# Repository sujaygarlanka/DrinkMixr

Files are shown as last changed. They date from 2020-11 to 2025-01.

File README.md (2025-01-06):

# DrinkMixr



A friend and I built a drink mixing machine that can dispense up to 4 liquids with half an ounce accuracy in any combination. There are three parts to this project.
- [Drink Machine](#drink-machine)
- [Mobile App](#mobile-app)
- [API](#api)

## Drink Machine
A physical machine that is 3D printed and MDF cut and contains tubing and motors controlled by a Raspberry Pi. It runs embedded python code that can be found [here](https://github.com/sujaygarlanka/DrinkMixr-Raspberry-Pi).

Final Machine              |  3D Model
:-------------------------:|:-------------------------:
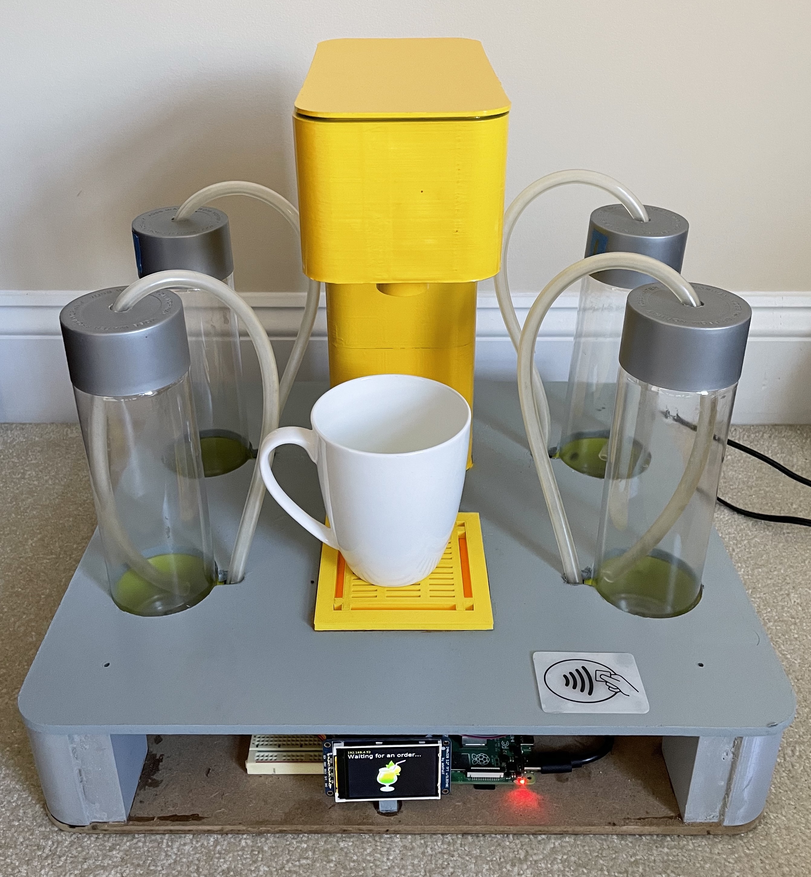
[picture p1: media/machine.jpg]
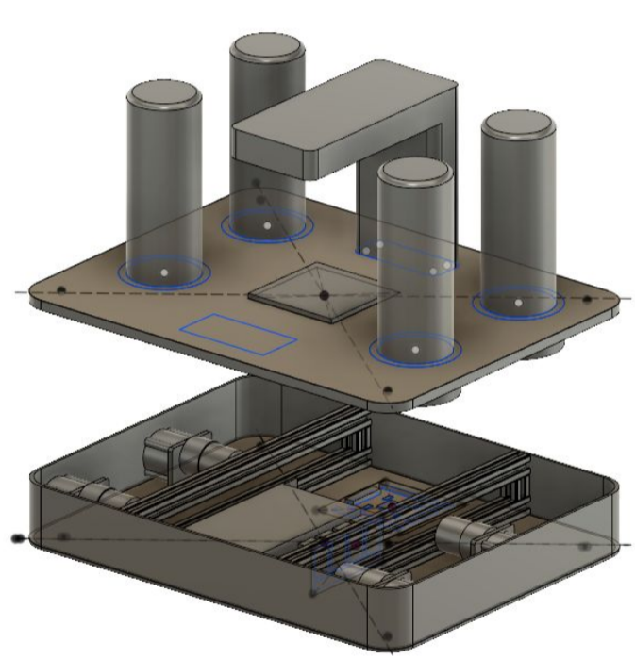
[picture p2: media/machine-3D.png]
 |  

## Mobile App


A mobile built in React Native that allows you to customize, save and send recipes to the drink machine when you tap your phone to the machine. Code for the 
app can be found [here](https://github.com/sujaygarlanka/DrinkMixr/tree/master/mobile_app).

## API
An API written in Python Flask running on a heroku server that accepts orders sent from the mobile app, queues them and sends them to the machine when it is ready to dispense. This API also handles the creation of users, tracking how much a user drinks, storing machine settings, etc. The API uses a MongoDB database to store all information.

### API Doc:
```python
@app.route('/order', methods=['GET'])
def getOrder():
    """
    GET /order
    Get the first order in the queue.

    Returns:
        JSON: The first order in the queue.
    """
    pass

@app.route('/order', methods=['POST'])
def addOrder():
    """
    POST /order
    Add an order to the end of the queue.

    Request Body:
        JSON: The order details.

    Returns:
        200 OK: If the order was successfully added.
        400 Bad Request: If the order data is missing or invalid.
    """
    pass

@app.route('/user', methods=['POST'])
def createUser():
    """
    POST /user
    Create a new user.

    Request Body:
        JSON: Contains the user's name.

    Returns:
        200 OK: If the user was successfully created.
        400 Bad Request: If the name is missing in the request body.
    """
    pass

@app.route('/configuration', methods=['GET'])
def getConfiguration():
    """
    GET /configuration
    Get the current Drink Mixr ingredients and motor configurations.

    Returns:
        JSON: The current configuration.
        200 OK: If the configuration is successfully retrieved.
    """
    pass

@app.route('/ingredients', methods=['PUT'])
def updateIngredients():
    """
    PUT /ingredients
    Update the ingredients in the Drink Mixr.

    Request Body:
        JSON: The updated ingredient list.

    Returns:
        204 No Content: If the update was successful.
    """
    pass

@app.route('/motors', methods=['PUT'])
def updateMotors():
    """
    PUT /motors
    Update the motor configurations in the Drink Mixr.

    Request Body:
        JSON: The updated motor configurations.

    Returns:
        204 No Content: If the update was successful.
    """
    pass

@app.route('/tubes', methods=['PUT'])
def updateTubes():
    """
    PUT /tubes
    Update the volume in the Drink Mixr's tubes.

    Request Body:
        JSON: The updated tube volume information.

    Returns:
        204 No Content: If the update was successful.
    """
    pass

@app.route('/recipes', methods=['GET'])
def getRecipes():
    """
    GET /recipes
    Retrieve all recipes for a specific user.

    Query Parameters:
        user_name (str): The name of the user.

    Returns:
        JSON: A list of recipes for the specified user.
        200 OK: If the recipes are successfully retrieved.
        400 Bad Request: If the user name is missing.
    """
    pass

@app.route('/recipes', methods=['POST'])
def addRecipe():
    """
    POST /recipes
    Add or update a recipe for a user.

    Query Parameters:
        user_name (str): The name of the user.

    Request Body:
        JSON: The recipe details.

    Returns:
        JSON: Confirmation of the added or updated recipe.
        200 OK: If the operation was successful.
        400 Bad Request: If the user name is missing.
    """
    pass

@app.route('/recipes', methods=['DELETE'])
def deleteRecipe():
    """
    DELETE /recipes
    Delete a specific recipe for a user.

    Query Parameters:
        user_name (str): The name of the user.
        recipe_name (str): The name of the recipe to delete.

    Returns:
        JSON: Confirmation of the deleted recipe.
        200 OK: If the recipe is successfully deleted.
        400 Bad Request: If the user name or recipe name is missing.
    """
    pass
```

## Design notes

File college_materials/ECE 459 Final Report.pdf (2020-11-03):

## Final Report

Final system specifications

The idea of the project is to build a drinker mixer machine that allows users to create and order drink recipes using an iOS app that communicates with a server that sends the order to an Arduino which then controls four pumps to dispense liquid into a cup.

The user can use the phone app save, edit, and delete custom recipes and order drinks based off these recipes. When a user wants to make an order, he/she taps their phone to an NFC tag that allows the app to send an order to a server. The Arduino Uno R3 uses a WiFi module that reads orders from the server and the Arduino parses the data to control the appropriate peristaltic pumps based on the ingredients in the order. During drink order processing, the order details are shown through a TFT display and prompts the user to place a cup under the nozzle. The cup is detected using a ultrasonic sensor. The volume of liquid dispensed will be controlled by the microcontroller via timers. Additionally, the TFT display shows user data such as total amount consumed.

Key progress from previous week

Over the previous week, we soldered all of our components onto our PCB and built the final chassis. Building the final chassis included laser cutting out top, bottom, and sides of our base. In addition, we 3D printed the neck and head. We also updated the phone app to support adding, saving, editing, and deleting recipes. Finally, we integrated all of the components with the chassis.

Open problems

The biggest open problem we have is not being able to accurately dispense when the motors are on. We suspect that this is due to interference with the Arduino through a common ground between the motors, power supply, and Arduino. When the relays are not connected to the common ground, the timing of the motors are accurate. Our efforts to resolve this would be to separate the grounds of the 15V power supply, buck converter and Arduino.

Currently, the output of the flow sensors are not accurate when the motors are running, we the motors are disconnected, the flow sensors perform as expected. We found there was interference from the common ground between the motors and the Arduino. We tried using tinfoil to act as a radiant shield for the signal wire but that did not work well.

We are limited to sending a payload of 64 bytes from the WiFi module to the serial buffer of the Arduino. We tried to read the payload as the WiFi module was sending it but were unable to find a consistent, working solution.

Testing & Results
- Accuracy tests were conducted for several volume amounts for water and juice.
- Timing and flow sensor methods were tested (timing was more accurate)
- Surface tension was achieved for 1 oz to 1 cup for various combinations of water volumes
- We confirmed pumping accuracy within 0.1 oz for water
- We used Postman to send HTTP requests to test the server side processing.

Robustness

The phone app checks for invalid data in volume field for recipes and any recipe name with ASCII characters is supported. The app converts spaces to underscores in order to send valid HTTP requests. Currently, the machine does not keep track of source volume so it does not detect when the source is empty or when the user orders a drink that has more volume than the source. Also, if a recipe has an ingredient an ingredient not in stock, the app currently does not check for that. This can be easily implemented by fetching from the database which items are in stock and check with the order when the user hits send.

Final vs. Initial Specifications:
- Server: The server used to process HTTP requests is a Python Flask server (https://stark-beach-45459.herokuapp.com/). A MongoDB database stores user recipes, amount consumed, ingredients, and orders. Our goal was to make are endpoints work correctly, and there are currently no bugs we have found. The following endpoints were created:
- GET /order
- POST /order
- POST /user
- GET /ingredients
- GET /recipes
- POST /recipes
- DELETE /recipes
- Mobile App: we created an iOS app that the user interfaces with to create, edit, delete and send custom recipes as drink orders. If the user wants to add a new recipe, they start from a template recipe that contains all of the ingredients in stock and they can change the volumes. This was our goal initially and were able to achieve it. One significant change we made involved using the phone as a reader vs. as a tag. Initially, the idea was to use an NFC reader to read the phone’s RFID tag and send data through NFC. We found it was not possible to do this with our phones (it could be done with a Nexus 5). We switched to using the phone as a reader and send data through WiFi. This turned out to be easier to facilitate communication between the phone, server, and Arduino.

- PCB: our PCB is used to integrate our Arduino with its peripherals in a compact, robust fashion. We used header pins to mount the Arduino, WiFi module, and buck converter. We soldered the rest of the components via wires. Ideally, we would want to recreate our own Arduino but our general goal was to integrate without a breadboard and this goal was met.
- Chassis: the chassis was designed to house all electrical components in an enclosed basement chamber that doubles as the main frame of the device. The peristaltic pumps reside in this basement as well, with their tubing routed through the hollow neck of the device. To house liquid ingredients, there are four plastic cylindrical reservoirs that flank the center dispenser console. These containers are supported by 3D-printed support frames that are integrated into the basement chamber. A beverage plate resides at the center of the device that serves as an outlet for any leaks and drippage that occurs after dispensing.

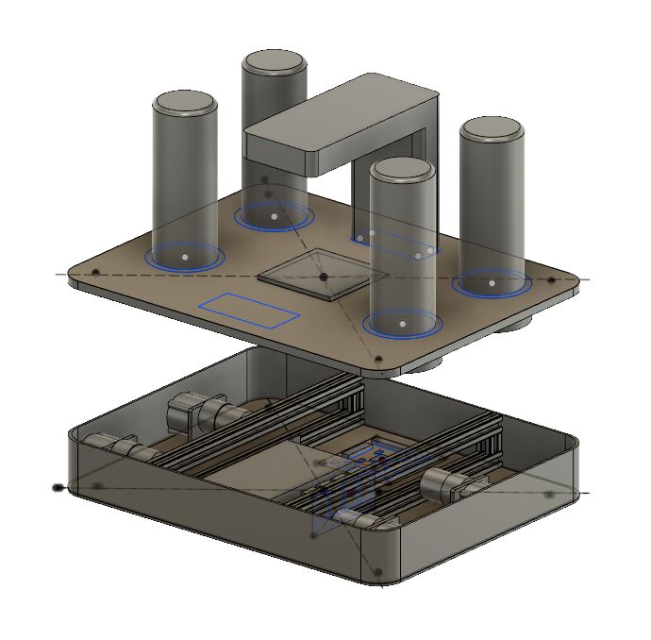
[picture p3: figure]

Safety considerations

The tubing is food safe and the sealant used at the bottom of the sources is also food safe. Given more time, we would fully isolate the electrical components from the food components like the tubing.

Final Gantt Chart

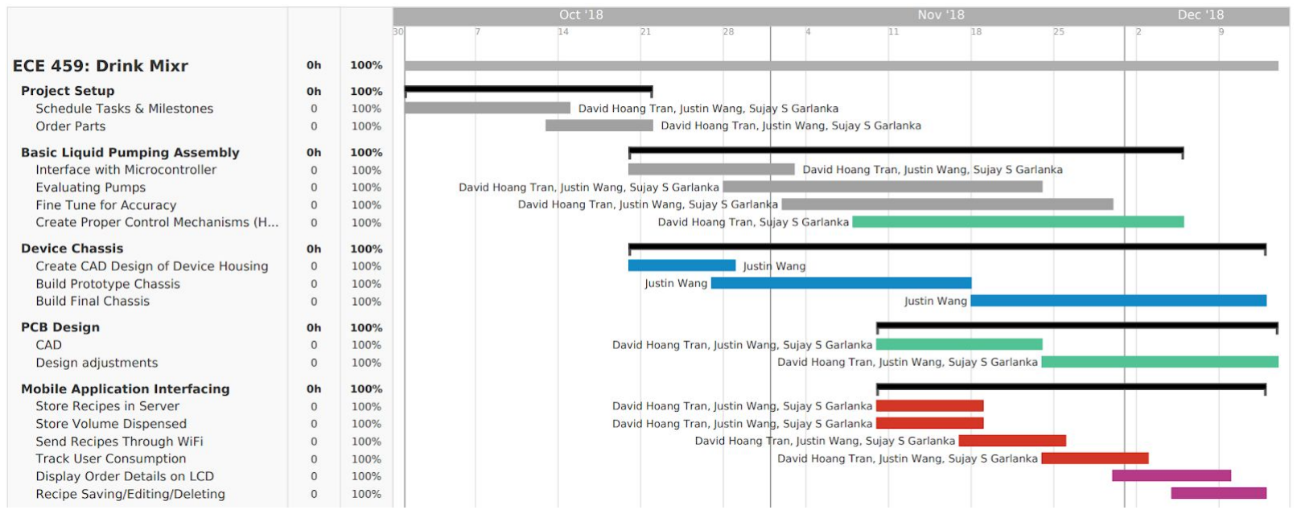
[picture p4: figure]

Final vs Initial Gantt chart
- Deviations: We added more subtasks for the phone app in order to organize developing the recipe customization. We needed to extend the deadline for testing & fine tuning flow meters since we wanted to use the temperature flow meters for liquids of different viscosity. We also extended the deadline for final chassis because it took longer than expected due to 3D print times and laser cutting issues.

Final budget
- Total spent: $520
- Cost to reproduce: $421

Technical problems encountered (and how were they overcome)

- Payload parsing: The server sends an order to the Arduino as a string of 64 bytes. An example payload would be
$O:robot-456.3:water_0-0-14.575:water_1-1-5.0:water_2-2-2.7:$. The format of the payload is “O:user_name-amount drank-ingredient-motor number-dispense time (sec):[additional ingredient entries]”. Here, robot is the name of the user and 456.3 is the total about consumed by the user. water_0 is the name of the ingredient, 0 is the motor number, and 14.575 is the dispense time of this ingredient in seconds. We parse the input by splitting by colons and dashes.
- Pumping accuracy with motors powered on: we ran into an issue with motor accuracy whenever we connected the motors to the 15V power supply. We believed the issue was caused by interference with the Arduino through a common ground between the motor and Arduino grounds.
- Parallel motor controls: we solved the problem of running motors simultaneously by keeping track of when a motor has been turned on. This was done in the Arduino code by storing the timestamp at which a motor turned on and iteratively checking each motor’s start time with the current timestamp.
- App functionality: a technical problem we resolve involved keeping the app up to date whenever the user creates/edits/deletes a recipe. We added a save button so that the user can either discard unsaved changes or save them. Whenever a user deletes a recipe, the page automatically returns to the home screen with the recipe deleted. Making sure the home screen has a correct list always was a challenge due to HTTP requests taking longer than page switching. We need to make sure the app waits for the request to complete or refresh the page automatically once it completes.

Rev 2.0
- Use H-bridges for reverse flow in order to save liquid in the tube and prevent contamination.
- Transfer bigger recipes by partitioning payload or be able to read payload as it’s being sent from WiFi module to the serial buffer.
- Not use a T-junction and use four flow sensors, which enables four motors to be run in parallel.

Member contributions
- Sujay
- Integrated Wifi module, TFT display and relays with the Arduino
- Helped design PCB
- Set up Python Flask server for the API
- Developed NFC functionality of the mobile app
- Justin
- Developed a prototype and final chassis
- Design of the liquid reservoir pipeline
- Component design and selection
- Tested thermal mass flow rate sensors
- David
- Developed the PCB schematic and layout using Eagle.
- Developed interface and functionality of the mobile app allowing users to create, edit, delete, and send orders.
- Helped test NFC for the original plan of reading RFID tags in phones
- Helped test accuracy of pumps and flow sensor signalling

Components:

power supply | 14.99
4 channel relay | 7.86
4 pumps | 123.58
1 tube | 9.99
2 flow meters | 45.48
arduino uno | 10
5V regulator | 9.99
variable buck converter | 7.99
TFT LCD | 31.28
wifi module (huzzah) | 16.95
4 VOSS bottles | 5
PING | 10
PCB | 27.88
Chassis parts | 100
h-bridges | 30
RC522 | 5.49
large flow meter | 19.64
expensive flow meters (2) | 74
DIYall ESP8266 | 6.99
Additional tubing | 20
4 wifi modules (Maker focus) | 13.99

ESP8266 802.11 (Adafruit) 14.93

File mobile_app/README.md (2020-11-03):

# Drink Mixr App

Special Steps Taken
------
- Add to react native vector icons to project
    - https://github.com/oblador/react-native-vector-icons#ios
- Google Sign In

UI
------
React Native Paper
- https://callstack.github.io/react-native-paper/getting-started.html

Galio
- https://github.com/galio-org/galio
- https://github.com/galio-org/galio-starter-kit

Authentication 
------
Google Sign In
- https://www.npmjs.com/package/react-native-google-signin
- https://aboutreact.com/example-of-google-sign-in-in-react-native/

React Native - Tutorials
------
App Organization
- https://medium.com/the-react-native-log/organizing-a-react-native-project-9514dfadaa0

Props and State in React.js
- https://www.youtube.com/watch?v=_D1JGNidMr4

React Navigation
- https://facebook.github.io/react-native/docs/navigation#react-navigation
https://alligator.io/react/react-native-navigation/

Authentication
- https://blog.usejournal.com/persisting-user-authentication-in-a-react-native-app-778e028ac816
- https://reactnavigation.org/docs/auth-flow/
- https://github.com/facebook/react-native-fbsdk

Redux
- https://www.youtube.com/watch?v=KTOoHu7kJTY

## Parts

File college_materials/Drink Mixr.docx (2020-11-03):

# Parts and Materials

Pumping System:

Part | Quantity | Cost ($) | Delivery Status
Power Supply (https://www.amazon.com/SMAKN-Adaptor-Transformers-adapters-chargers/dp/B0754X9P3N) | 1 | 14.99 | Delivered
Power Distribution (https://www.amazon.com/gp/product/B01CU66VM2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) | 1 | 16.50 | Delivered
H-Bridges (https://www.digikey.com/product-detail/en/adafruit-industries-llc/3190/1528-1719-ND/6138098?WT.srch=1) | 4 | 30 | Delivered
Persistaltic Pump (https://www.ebay.com/itm/12V-400ml-min-Peristaltic-Pump-Dosing-Pump-Vacuum-Aquarium-Lab-Analytical-Water/122421770219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) Other Motor (https://www.ebay.com/itm/DC-12V-400ml-min-Aquarium-Lab-AnalyticaDosing-Pump-Peristaltic-Pump-For-l-Water/263975802514) | 3 1 | 123.58 | Delivered

Electronics:

Part | Quantity | Cost ($) | Delivery Status
Arduino | 1 | 10 | Delivered
PN532 (https://www.amazon.com/gp/product/B00KKUECAO/ref=od_aui_detailpages00?ie=UTF8&psc=1) (NFC) | 1 | 37.97 | Delivered
RC522 (https://www.amazon.com/gp/product/B01CSTW0IA/ref=oh_aui_detailpage_o06_s00?ie=UTF8&psc=1) (NFC) | 1 | 5.49 | Delivered
TFT Display (https://www.adafruit.com/product/1480) | 1 | 31.28 | Expected Delivery Monday
5V Regulator (https://www.adafruit.com/product/1385) | 1 | 9.95 | Delivered
Flow Rate Meter (https://www.digikey.com/product-detail/en/314150001/1597-1615-ND/5488169?so=57078285) | 2 | 45.48 | Delivered
Flow Rate Sensor (Adafruit) (https://www.adafruit.com/product/828) | 1 | 19.64 | Delivered
Flow Rate Meters | 2 | 74 | Delivered
Relays (co-lab) | 2 | 4 | Delivered
4 Channel Relay (https://www.amazon.com/dp/B01HEQF5HU/ref=biss_dp_t_asn) | 1 | 7.86 | Expected Delivery Friday
WiFi Module (https://www.amazon.com/DIYmall-ESP8266-ESP-01S-Serial-Transceiver/dp/B00O34AGSU) (Feather Huzzah) | 1 | 16.95 (Ocean Engineering) | Delivered
PING Sensor | 1 | 10 (Bingham) | Delivered
DIYmall ESP8266 ESP-01S (https://www.amazon.com/gp/product/B00O34AGSU/ref=oh_aui_detailpage_o02_s00?ie=UTF8&psc=1) | 1 | 6.99 | Delivered
4 WIFI Modules (Makerfocus) (https://www.amazon.com/Makerfocus-ESP8266-ESP-01S-Transceiver-Arduino/dp/B01N98BTRH?s=electronics) | 1 | 13.99 | Expected Delivery Saturday
Adafruit ESP8266 802.11 (https://www.amazon.com/gp/product/B0131V0WYI/ref=oh_aui_detailpage_o01_s00?ie=UTF8&psc=1) | 1 | 14.93 | Delivered
Variable Buck Converter (https://www.amazon.com/gp/product/B00SY37S00/ref=oh_aui_detailpage_o00_s00?ie=UTF8&psc=1) | 1 | 7.99 | Expected Delivery Friday

Chassis:

Part | Quantity | Cost ($) | Delivery Status
Silicon Tubing (https://www.amazon.com/gp/product/B0754KH4KP/ref=oh_aui_detailpage_o05_s00?ie=UTF8&psc=1) (too large) | 1 | 12.99 | Delivered
Silicon Tubing (https://www.amazon.com/gp/product/B01N3QTNTM/ref=oh_aui_detailpage_o00_s00?ie=UTF8&psc=1) (right size, not food safe) | 1 | 7.29 | Delivered
Silicon Tubing (3/16”, 10 ft) (https://www.amazon.com/gp/product/B017EA5ST6/ref=oh_aui_detailpage_o00_s00?ie=UTF8&psc=1) - too thick | 1 | 8.69 | Delivered
Vinyl Tubing (1/4“) | 1 | 21.00 | Delivered
Silicon Tubing (4mm ID, food safe) (https://www.amazon.com/Silicone-Tubing-16-ID-Wall/dp/B079X1S5WP?s=industrial) | 1 | 9.99 | Expected Tuesday Dec. 2
Funnel (https://www.amazon.com/gp/product/B01NH53RBH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) | 1 | 8.98 | Need to order/make
Old Bottles | 6 | 18 | Delivered
New Bottles | 4 | 15 | Delivered

Total Spent: $696

Cost to rebuild: $420.99

# Reimbursement

David:

Part | Cost ($)
Peristaltic Pumps (3) | 92.64
Silicon Tubing (3/16”, 10 ft) (https://www.amazon.com/gp/product/B017EA5ST6/ref=oh_aui_detailpage_o00_s00?ie=UTF8&psc=1) | 8.69
Best Tubing (1/4“) | 21.00
DIYmall ESP8266 ESP-01S (https://www.amazon.com/gp/product/B00O34AGSU/ref=oh_aui_detailpage_o02_s00?ie=UTF8&psc=1) | 6.99
ESP8266 802.11 (https://www.amazon.com/gp/product/B0131V0WYI/ref=oh_aui_detailpage_o01_s00?ie=UTF8&psc=1) | 14.93

Sujay

Part | Cost ($)
Peristaltic Pump | 30.88
Silicon Tubing (large and plasticky) | 12.99
Silicon Tubing (rubbery and on Amazon) | 7.29
Flow Rate Sensor (Digikey) (Ebay) | 22.74
Flow Rate Sensor (Adafruit) | 19.64
PN532 | 37.97
Relay | 2
Variable Buck Converter | 7.99
4 Channel Relay | 7.86
TFT Display | 31.28

Justin:

Part | Cost
Bottles | ?

# Need to Return

Part | Cost
Flow Rate Sensor (Adafruit) | 19.64
NFC Reader (https://www.amazon.com/gp/product/B00KKUECAO/ref=od_aui_detailpages00?ie=UTF8&psc=1) | 39.97
DIYmall ESP8266 ESP-01S (https://www.amazon.com/gp/product/B00O34AGSU/ref=oh_aui_detailpage_o02_s00?ie=UTF8&psc=1) | 6.99
ESP8266 802.11 (https://www.amazon.com/gp/product/B0131V0WYI/ref=oh_aui_detailpage_o01_s00?ie=UTF8&psc=1) | 14.93
Silicon Tubing (3/16”, 10 ft) (https://www.amazon.com/gp/product/B017EA5ST6/ref=oh_aui_detailpage_o00_s00?ie=UTF8&psc=1) - too thick | 8.69

# Useful Links

Hacker Shack Drink Mixer (good parts reference): https://www.youtube.com/watch?v=2DopvpNF7J4&t=486s

GreatScott! Cocktail Machine (400ml/min motors): https://www.youtube.com/watch?v=Z7GkGeZrb2Y&t=417s

Wifi Module:

https://medium.com/@cgrant/using-the-esp8266-wifi-module-with-arduino-uno-publishing-to-thingspeak-99fc77122e82

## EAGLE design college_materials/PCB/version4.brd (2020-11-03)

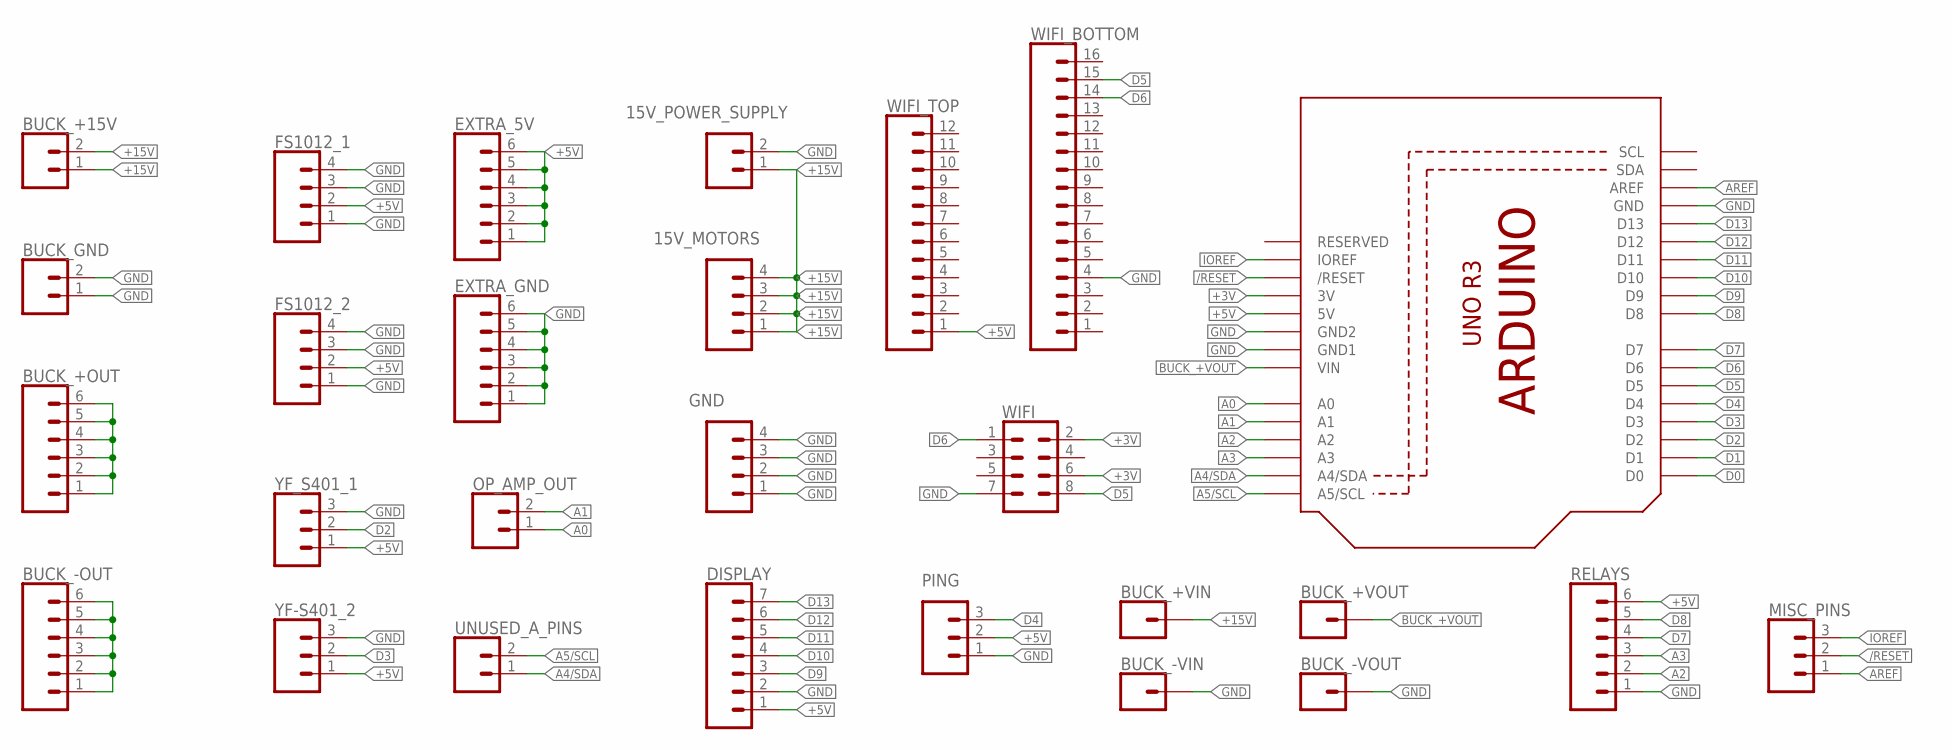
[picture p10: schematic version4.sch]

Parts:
15V_MOTORS: CONN_04; 1X04
15V_POWER_SUPPLY: CONN_02; 1X02
BUCK_+15V: CONN_02; 1X02
BUCK_+OUT: CONN_06SILK_FEMALE_PTH; 1X06
BUCK_+VIN: CONN_01; 1X01
BUCK_+VOUT: CONN_01; 1X01
BUCK_-OUT: CONN_06SILK_FEMALE_PTH; 1X06
BUCK_-VIN: CONN_01; 1X01
BUCK_-VOUT: CONN_01; 1X01
BUCK_GND: CONN_02; 1X02
DISPLAY: CONN_07; 1X07
EXTRA_5V: CONN_06SILK_FEMALE_PTH; 1X06
EXTRA_GND: CONN_06SILK_FEMALE_PTH; 1X06
FS1012_1, FS1012_2: CONN_04; 1X04
GND: CONN_04; 1X04
MISC_PINS: CONN_03; 1X03
OP_AMP_OUT: CONN_02; 1X02
PING: CONN_03; 1X03
RELAYS: CONN_06SILK_FEMALE_PTH; 1X06
U1: ARDUINOR3-BPLACE
UNUSED_A_PINS: CONN_02; 1X02
WIFI: CONN_04X2; 2X4
WIFI_BOTTOM: CONN_16; 1X16
WIFI_TOP: CONN_12; 1X12
YF-S401_2: CONN_03; 1X03
YF_S401_1: CONN_03; 1X03

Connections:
+3V: U1.3V, WIFI.2, WIFI.6
+5V: DISPLAY.1, EXTRA_5V.1, EXTRA_5V.2, EXTRA_5V.3, EXTRA_5V.4, EXTRA_5V.5, EXTRA_5V.6, FS1012_1.2, FS1012_2.2, PING.2, RELAYS.6, U1.5V, WIFI_TOP.1, YF-S401_2.1, YF_S401_1.1
+15V: 15V_MOTORS.1, 15V_MOTORS.2, 15V_MOTORS.3, 15V_MOTORS.4, 15V_POWER_SUPPLY.1, BUCK_+15V.1, BUCK_+15V.2, BUCK_+VIN.1
/RESET: MISC_PINS.2, U1.RESET (/RESET)
A0: OP_AMP_OUT.1, U1.A0
A1: OP_AMP_OUT.2, U1.A1
A2: RELAYS.2, U1.A2
A3: RELAYS.3, U1.A3
A4/SDA: U1.A4 (A4/SDA), UNUSED_A_PINS.1
A5/SCL: U1.A5 (A5/SCL), UNUSED_A_PINS.2
AREF: MISC_PINS.1, U1.AREF
BUCK_+VOUT: BUCK_+VOUT.1, U1.VIN
D0: U1.D0
D1: U1.D1
D2: U1.D2, YF_S401_1.2
D3: U1.D3, YF-S401_2.2
D4: PING.3, U1.D4
D5: U1.D5, WIFI.8, WIFI_BOTTOM.15
D6: U1.D6, WIFI.1, WIFI_BOTTOM.14
D7: RELAYS.4, U1.D7
D8: RELAYS.5, U1.D8
D9: DISPLAY.3, U1.D9
D10: DISPLAY.4, U1.D10
D11: DISPLAY.5, U1.D11
D12: DISPLAY.6, U1.D12
D13: DISPLAY.7, U1.D13
GND: 15V_POWER_SUPPLY.2, BUCK_-VIN.1, BUCK_-VOUT.1, BUCK_GND.1, BUCK_GND.2, DISPLAY.2, EXTRA_GND.1, EXTRA_GND.2, EXTRA_GND.3, EXTRA_GND.4, EXTRA_GND.5, EXTRA_GND.6, FS1012_1.1, FS1012_1.3, FS1012_1.4, FS1012_2.1, FS1012_2.3, FS1012_2.4, GND.1, GND.2, GND.3, GND.4, PING.1, RELAYS.1, U1.GND, U1.GND1, U1.GND2, WIFI.7, WIFI_BOTTOM.4, YF-S401_2.3, YF_S401_1.3
IOREF: MISC_PINS.3, U1.IOREF
unnamed: BUCK_+OUT.1, BUCK_+OUT.2, BUCK_+OUT.3, BUCK_+OUT.4, BUCK_+OUT.5, BUCK_+OUT.6
unnamed: BUCK_-OUT.1, BUCK_-OUT.2, BUCK_-OUT.3, BUCK_-OUT.4, BUCK_-OUT.5, BUCK_-OUT.6

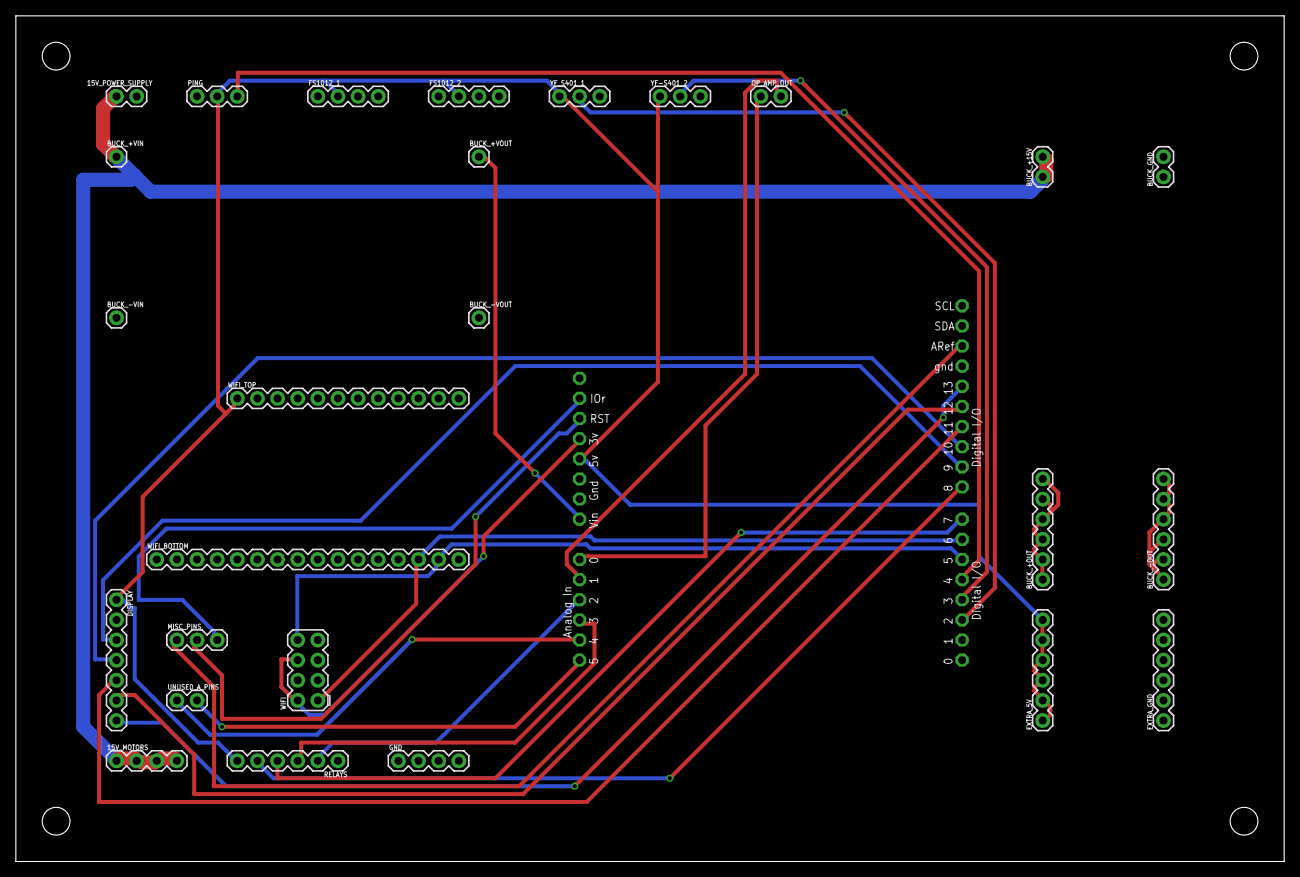
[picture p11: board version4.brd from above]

Board: 2 copper layers, 160.0 x 106.7 mm, 27 parts (0 on the bottom side), 28 nets.

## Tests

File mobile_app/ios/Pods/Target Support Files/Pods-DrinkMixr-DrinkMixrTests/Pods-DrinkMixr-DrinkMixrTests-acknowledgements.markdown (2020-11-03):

# Acknowledgements
This application makes use of the following third party libraries:

## AppAuth

                                 Apache License
                           Version 2.0, January 2004
                        http://www.apache.org/licenses/

   TERMS AND CONDITIONS FOR USE, REPRODUCTION, AND DISTRIBUTION

   1. Definitions.

      "License" shall mean the terms and conditions for use, reproduction,
      and distribution as defined by Sections 1 through 9 of this document.

      "Licensor" shall mean the copyright owner or entity authorized by
      the copyright owner that is granting the License.

      "Legal Entity" shall mean the union of the acting entity and all
      other entities that control, are controlled by, or are under common
      control with that entity. For the purposes of this definition,
      "control" means (i) the power, direct or indirect, to cause the
      direction or management of such entity, whether by contract or
      otherwise, or (ii) ownership of fifty percent (50%) or more of the
      outstanding shares, or (iii) beneficial ownership of such entity.

      "You" (or "Your") shall mean an individual or Legal Entity
      exercising permissions granted by this License.

      "Source" form shall mean the preferred form for making modifications,
      including but not limited to software source code, documentation
      source, and configuration files.

      "Object" form shall mean any form resulting from mechanical
      transformation or translation of a Source form, including but
      not limited to compiled object code, generated documentation,
      and conversions to other media types.

      "Work" shall mean the work of authorship, whether in Source or
      Object form, made available under the License, as indicated by a
      copyright notice that is included in or attached to the work
      (an example is provided in the Appendix below).

      "Derivative Works" shall mean any work, whether in Source or Object
      form, that is based on (or derived from) the Work and for which the
      editorial revisions, annotations, elaborations, or other modifications
      represent, as a whole, an original work of authorship. For the purposes
      of this License, Derivative Works shall not include works that remain
      separable from, or merely link (or bind by name) to the interfaces of,
      the Work and Derivative Works thereof.

      "Contribution" shall mean any work of authorship, including
      the original version of the Work and any modifications or additions
      to that Work or Derivative Works thereof, that is intentionally
      submitted to Licensor for inclusion in the Work by the copyright owner
      or by an individual or Legal Entity authorized to submit on behalf of
      the copyright owner. For the purposes of this definition, "submitted"
      means any form of electronic, verbal, or written communication sent
      to the Licensor or its representatives, including but not limited to
      communication on electronic mailing lists, source code control systems,
      and issue tracking systems that are managed by, or on behalf of, the
      Licensor for the purpose of discussing and improving the Work, but
      excluding communication that is conspicuously marked or otherwise
      designated in writing by the copyright owner as "Not a Contribution."

      "Contributor" shall mean Licensor and any individual or Legal Entity
      on behalf of whom a Contribution has been received by Licensor and
      subsequently incorporated within the Work.

   2. Grant of Copyright License. Subject to the terms and conditions of
      this License, each Contributor hereby grants to You a perpetual,
      worldwide, non-exclusive, no-charge, royalty-free, irrevocable
      copyright license to reproduce, prepare Derivative Works of,
      publicly display, publicly perform, sublicense, and distribute the
      Work and such Derivative Works in Source or Object form.

   3. Grant of Patent License. Subject to the terms and conditions of
      this License, each Contributor hereby grants to You a perpetual,
      worldwide, non-exclusive, no-charge, royalty-free, irrevocable
      (except as stated in this section) patent license to make, have made,
      use, offer to sell, sell, import, and otherwise transfer the Work,
      where such license applies only to those patent claims licensable
      by such Contributor that are necessarily infringed by their
      Contribution(s) alone or by combination of their Contribution(s)
      with the Work to which such Contribution(s) was submitted. If You
      institute patent litigation against any entity (including a
      cross-claim or counterclaim in a lawsuit) alleging that the Work
      or a Contribution incorporated within the Work constitutes direct
      or contributory patent infringement, then any patent licenses
      granted to You under this License for that Work shall terminate
      as of the date such litigation is filed.

   4. Redistribution. You may reproduce and distribute copies of the
      Work or Derivative Works thereof in any medium, with or without
      modifications, and in Source or Object form, provided that You
      meet the following conditions:

      (a) You must give any other recipients of the Work or
          Derivative Works a copy of this License; and

      (b) You must cause any modified files to carry prominent notices
          stating that You changed the files; and

      (c) You must retain, in the Source form of any Derivative Works
          that You distribute, all copyright, patent, trademark, and
          attribution notices from the Source form of the Work,
          excluding those notices that do not pertain to any part of
          the Derivative Works; and

      (d) If the Work includes a "NOTICE" text file as part of its
          distribution, then any Derivative Works that You distribute must
          include a readable copy of the attribution notices contained
          within such NOTICE file, excluding those notices that do not
          pertain to any part of the Derivative Works, in at least one
          of the following places: within a NOTICE text file distributed
          as part of the Derivative Works; within the Source form or
          documentation, if provided along with the Derivative Works; or,
          within a display generated by the Derivative Works, if and
          wherever such third-party notices normally appear. The contents
          of the NOTICE file are for informational purposes only and
          do not modify the License. You may add Your own attribution
          notices within Derivative Works that You distribute, alongside
          or as an addendum to the NOTICE text from the Work, provided
          that such additional attribution notices cannot be construed
          as modifying the License.

      You may add Your own copyright statement to Your modifications and
      may provide additional or different license terms and conditions
      for use, reproduction, or distribution of Your modifications, or
      for any such Derivative Works as a whole, provided Your use,
      reproduction, and distribution of the Work otherwise complies with
      the conditions stated in this License.

   5. Submission of Contributions. Unless You explicitly state otherwise,
      any Contribution intentionally submitted for inclusion in the Work
      by You to the Licensor shall be under the terms and conditions of
      this License, without any additional terms or conditions.
      Notwithstanding the above, nothing herein shall supersede or modify
      the terms of any separate license agreement you may have executed
      with Licensor regarding such Contributions.

   6. Trademarks. This License does not grant permission to use the trade
      names, trademarks, service marks, or product names of the Licensor,
      except as required for reasonable and customary use in describing the
      origin of the Work and reproducing the content of the NOTICE file.

   7. Disclaimer of Warranty. Unless required by applicable law or
      agreed to in writing, Licensor provides the Work (and each
      Contributor provides its Contributions) on an "AS IS" BASIS,
      WITHOUT WARRANTIES OR CONDITIONS OF ANY KIND, either express or
      implied, including, without limitation, any warranties or conditions
      of TITLE, NON-INFRINGEMENT, MERCHANTABILITY, or FITNESS FOR A
      PARTICULAR PURPOSE. You are solely responsible for determining the
      appropriateness of using or redistributing the Work and assume any
      risks associated with Your exercise of permissions under this License.

   8. Limitation of Liability. In no event and under no legal theory,
      whether in tort (including negligence), contract, or otherwise,
      unless required by applicable law (such as deliberate and grossly
      negligent acts) or agreed to in writing, shall any Contributor be
      liable to You for damages, including any direct, indirect, special,
      incidental, or consequential damages of any character arising as a
      result of this License or out of the use or inability to use the
      Work (including but not limited to damages for loss of goodwill,
      work stoppage, computer failure or malfunction, or any and all
      other commercial damages or losses), even if such Contributor
      has been advised of the possibility of such damages.

   9. Accepting Warranty or Additional Liability. While redistributing
      the Work or Derivative Works thereof, You may choose to offer,
      and charge a fee for, acceptance of support, warranty, indemnity,
      or other liability obligations and/or rights consistent with this
      License. However, in accepting such obligations, You may act only
      on Your own behalf and on Your sole responsibility, not on behalf
      of any other Contributor, and only if You agree to indemnify,
      defend, and hold each Contributor harmless for any liability
      incurred by, or claims asserted against, such Contributor by reason
      of your accepting any such warranty or additional liability.

   END OF TERMS AND CONDITIONS

   APPENDIX: How to apply the Apache License to your work.

      To apply the Apache License to your work, attach the following
      boilerplate notice, with the fields enclosed by brackets "[]"
      replaced with your own identifying information. (Don't include
      the brackets!)  The text should be enclosed in the appropriate
      comment syntax for the file format. We also recommend that a
      file or class name and description of purpose be included on the
      same "printed page" as the copyright notice for easier
      identification within third-party archives.

   Copyright [yyyy] [name of copyright owner]

   Licensed under the Apache License, Version 2.0 (the "License");
   you may not use this file except in compliance with the License.
   You may obtain a copy of the License at

       http://www.apache.org/licenses/LICENSE-2.0

   Unless required by applicable law or agreed to in writing, software
   distributed under the License is distributed on an "AS IS" BASIS,
   WITHOUT WARRANTIES OR CONDITIONS OF ANY KIND, either express or implied.
   See the License for the specific language governing permissions and
   limitations under the License.

## CocoaAsyncSocket

Public Domain License

The CocoaAsyncSocket project is in the public domain.

The original TCP version (AsyncSocket) was created by Dustin Voss in January 2003.
Updated and maintained by Deusty LLC and the Apple development community.

## CocoaLibEvent

Copyright (c) 2018 99789999@qq.com <99789999@qq.com>

Permission is hereby granted, free of charge, to any person obtaining a copy
of this software and associated documentation files (the "Software"), to deal
in the Software without restriction, including without limitation the rights
to use, copy, modify, merge, publish, distribute, sublicense, and/or sell
copies of the Software, and to permit persons to whom the Software is
furnished to do so, subject to the following conditions:

The above copyright notice and this permission notice shall be included in
all copies or substantial portions of the Software.

THE SOFTWARE IS PROVIDED "AS IS", WITHOUT WARRANTY OF ANY KIND, EXPRESS OR
IMPLIED, INCLUDING BUT NOT LIMITED TO THE WARRANTIES OF MERCHANTABILITY,
FITNESS FOR A PARTICULAR PURPOSE AND NONINFRINGEMENT. IN NO EVENT SHALL THE
AUTHORS OR COPYRIGHT HOLDERS BE LIABLE FOR ANY CLAIM, DAMAGES OR OTHER
LIABILITY, WHETHER IN AN ACTION OF CONTRACT, TORT OR OTHERWISE, ARISING FROM,
OUT OF OR IN CONNECTION WITH THE SOFTWARE OR THE USE OR OTHER DEALINGS IN
THE SOFTWARE.

## DoubleConversion

Copyright 2006-2011, the V8 project authors. All rights reserved.
Redistribution and use in source and binary forms, with or without
modification, are permitted provided that the following conditions are
met:

    * Redistributions of source code must retain the above copyright
      notice, this list of conditions and the following disclaimer.
    * Redistributions in binary form must reproduce the above
      copyright notice, this list of conditions and the following
      disclaimer in the documentation and/or other materials provided
      with the distribution.
    * Neither the name of Google Inc. nor the names of its
      contributors may be used to endorse or promote products derived
      from this software without specific prior written permission.

THIS SOFTWARE IS PROVIDED BY THE COPYRIGHT HOLDERS AND CONTRIBUTORS
"AS IS" AND ANY EXPRESS OR IMPLIED WARRANTIES, INCLUDING, BUT NOT
LIMITED TO, THE IMPLIED WARRANTIES OF MERCHANTABILITY AND FITNESS FOR
A PARTICULAR PURPOSE ARE DISCLAIMED. IN NO EVENT SHALL THE COPYRIGHT
OWNER OR CONTRIBUTORS BE LIABLE FOR ANY DIRECT, INDIRECT, INCIDENTAL,
SPECIAL, EXEMPLARY, OR CONSEQUENTIAL DAMAGES (INCLUDING, BUT NOT
LIMITED TO, PROCUREMENT OF SUBSTITUTE GOODS OR SERVICES; LOSS OF USE,
DATA, OR PROFITS; OR BUSINESS INTERRUPTION) HOWEVER CAUSED AND ON ANY
THEORY OF LIABILITY, WHETHER IN CONTRACT, STRICT LIABILITY, OR TORT
(INCLUDING NEGLIGENCE OR OTHERWISE) ARISING IN ANY WAY OUT OF THE USE
OF THIS SOFTWARE, EVEN IF ADVISED OF THE POSSIBILITY OF SUCH DAMAGE.

## Flipper

MIT License

Copyright (c) Facebook, Inc. and its affiliates.

Permission is hereby granted, free of charge, to any person obtaining a copy
of this software and associated documentation files (the "Software"), to deal
in the Software without restriction, including without limitation the rights
to use, copy, modify, merge, publish, distribute, sublicense, and/or sell
copies of the Software, and to permit persons to whom the Software is
furnished to do so, subject to the following conditions:

The above copyright notice and this permission notice shall be included in all
copies or substantial portions of the Software.

THE SOFTWARE IS PROVIDED "AS IS", WITHOUT WARRANTY OF ANY KIND, EXPRESS OR
IMPLIED, INCLUDING BUT NOT LIMITED TO THE WARRANTIES OF MERCHANTABILITY,
FITNESS FOR A PARTICULAR PURPOSE AND NONINFRINGEMENT. IN NO EVENT SHALL THE
AUTHORS OR COPYRIGHT HOLDERS BE LIABLE FOR ANY CLAIM, DAMAGES OR OTHER
LIABILITY, WHETHER IN AN ACTION OF CONTRACT, TORT OR OTHERWISE, ARISING FROM,
OUT OF OR IN CONNECTION WITH THE SOFTWARE OR THE USE OR OTHER DEALINGS IN THE
SOFTWARE.

## Flipper-DoubleConversion

Copyright 2006-2011, the V8 project authors. All rights reserved.
Redistribution and use in source and binary forms, with or without
modification, are permitted provided that the following conditions are
met:

    * Redistributions of source code must retain the above copyright
      notice, this list of conditions and the following disclaimer.
    * Redistributions in binary form must reproduce the above
      copyright notice, this list of conditions and the following
      disclaimer in the documentation and/or other materials provided
      with the distribution.
    * Neither the name of Google Inc. nor the names of its
      contributors may be used to endorse or promote products derived
      from this software without specific prior written permission.

THIS SOFTWARE IS PROVIDED BY THE COPYRIGHT HOLDERS AND CONTRIBUTORS
"AS IS" AND ANY EXPRESS OR IMPLIED WARRANTIES, INCLUDING, BUT NOT
LIMITED TO, THE IMPLIED WARRANTIES OF MERCHANTABILITY AND FITNESS FOR
A PARTICULAR PURPOSE ARE DISCLAIMED. IN NO EVENT SHALL THE COPYRIGHT
OWNER OR CONTRIBUTORS BE LIABLE FOR ANY DIRECT, INDIRECT, INCIDENTAL,
SPECIAL, EXEMPLARY, OR CONSEQUENTIAL DAMAGES (INCLUDING, BUT NOT
LIMITED TO, PROCUREMENT OF SUBSTITUTE GOODS OR SERVICES; LOSS OF USE,
DATA, OR PROFITS; OR BUSINESS INTERRUPTION) HOWEVER CAUSED AND ON ANY
THEORY OF LIABILITY, WHETHER IN CONTRACT, STRICT LIABILITY, OR TORT
(INCLUDING NEGLIGENCE OR OTHERWISE) ARISING IN ANY WAY OUT OF THE USE
OF THIS SOFTWARE, EVEN IF ADVISED OF THE POSSIBILITY OF SUCH DAMAGE.
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

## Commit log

2020-11-03 reorganize code
    [copper_bottom.gbr, copper_top.gbr, drills.xln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]
2020-11-03 rename folders
    [copper_bottom.gbr, copper_top.gbr, drills.xln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]

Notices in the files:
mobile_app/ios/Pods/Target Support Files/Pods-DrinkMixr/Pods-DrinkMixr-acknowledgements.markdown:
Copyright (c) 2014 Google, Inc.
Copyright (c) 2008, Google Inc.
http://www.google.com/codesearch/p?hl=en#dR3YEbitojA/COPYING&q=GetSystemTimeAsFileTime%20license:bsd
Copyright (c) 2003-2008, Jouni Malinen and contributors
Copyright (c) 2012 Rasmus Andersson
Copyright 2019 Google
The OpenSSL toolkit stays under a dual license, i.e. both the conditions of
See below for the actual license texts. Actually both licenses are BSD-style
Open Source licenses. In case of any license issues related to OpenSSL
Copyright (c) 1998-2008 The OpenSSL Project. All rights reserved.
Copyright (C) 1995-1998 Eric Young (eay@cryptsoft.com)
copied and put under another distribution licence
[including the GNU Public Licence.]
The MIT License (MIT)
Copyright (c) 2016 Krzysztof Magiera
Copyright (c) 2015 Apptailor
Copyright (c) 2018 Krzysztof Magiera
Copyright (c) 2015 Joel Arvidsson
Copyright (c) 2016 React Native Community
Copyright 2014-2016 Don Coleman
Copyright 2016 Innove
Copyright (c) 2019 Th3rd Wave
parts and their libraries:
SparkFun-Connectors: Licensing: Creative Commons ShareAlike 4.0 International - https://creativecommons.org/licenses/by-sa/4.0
